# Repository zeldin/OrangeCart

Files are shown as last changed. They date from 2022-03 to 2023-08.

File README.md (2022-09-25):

The Orange Cartridge -- an FPGA cartridge for the C64/C128
==========================================================

This is an open source hardware FPGA cartridge for the C64 and C128.
The main features are:
 * ECP5 FPGA with 24k LUTs and 126 KB of block RAM
 * 16 MB of HyperRAM
 * 16 MB of SPI NOR Flash
 * Full speed USB
 * Micro SD-card
 * RGB LED
 * Pushbutton

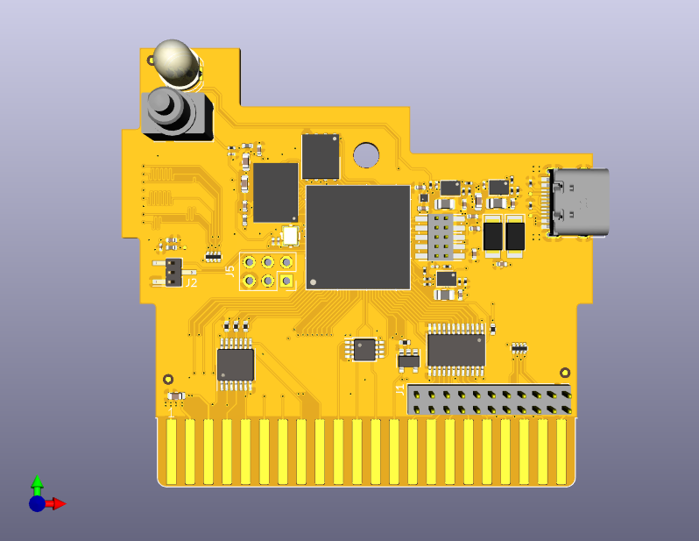
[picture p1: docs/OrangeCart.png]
Render of the PCBA


Usage
-----

For full usage instructions and other detailed information, please refer to
[the wiki][wiki].

The cartridge can be powered from the expansion port, from the USB connector,
or both at once (back-current protection diodes are present at each power
input).

To enter the bootloader, keep the pushbutton pressed down when applying
power.  The LED will start flashing in a rainbow pattern.  A new bitstream
can now be uploaded using DFU.

Example bitstreams
------------------

- [RVCop64](https://github.com/zeldin/RVCop64)
- [super-reu](https://github.com/zeldin/super-reu)

[wiki]: https://github.com/zeldin/OrangeCart/wiki

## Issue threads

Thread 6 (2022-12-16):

VIC access?

pottendo, 2022-12-16:
hi,
trying to control some VIC regs from RVCop64 firmware (bare metal, Zephyr, Linux) won't deliver the desired result.
It seems that the VIC registers aren't accessible reliably.
Attached my test program, derived from the oled example.
The access to video mem works, but the border color isn't changed - even worse, also the background is altered.
What am I doing wrong?

thx, pottendo
```
#include <stdio.h>
#include <stdlib.h>
#include <string.h>
#include <unistd.h>
#include <irq.h>
#include <libbase/uart.h>
#include <libbase/i2c.h>
#include <generated/csr.h>

volatile uint8_t *scr = (uint8_t*)0x00000420;
volatile uint8_t *vic = (uint8_t*)0x0000d000;
const int cnt = 3000;

int main(void)
{
#ifdef CONFIG_CPU_HAS_INTERRUPT
	irq_setmask(0);
	irq_setie(1);
#endif
	uart_init();
	uint8_t c = 0;
	volatile double f=1.2;
	printf("Starting...\n");
	*vic = 5;

	while (1)
	{
	    for (int i = 0; i < 128; i++)
	    {
		c = (c + 1) % 255;
		*(scr + i) = c;
		for (volatile int j = 0; j < cnt; j++)
		    ;
		(*vic) = ((*vic) + 1) % 16;
	    }
	    printf("hello world: %d, f=%f.\n", c, f);
	    f = f*1.033;
	}
	return 0;
}
```

zeldin, 2022-12-16:
Is this on regular RVCop or your SMP remix?  (And either way shouldn't the issue be opened in RVCop instead?)

When I run the commands
```
mem_write 0xd020 0xc 1 1
mem_write 0xd021 0x6 1 1
mem_read 0xd020 2 1
```
in `rvterm` on the release RVCop bitstream found on github, the results are the expected:
 * The first write changes only the border colour
 * The second write changes only the background colour
 * The read command reads back the values I wrote, but with the high nybble changed to 0xf
So I'd say VIC access is working fine.

Looking at your code, I don't see anything that attempts to change the border colour, only the colour of the first sprite?

pottendo, 2022-12-17:
Hi,
sorry, i've mixed up some of my experiments.
You're right, this test was around moving sprites - again attached my altered testprogram and here the demonstration:
  https://photos.app.goo.gl/WwHV2yNQAhuR5Moq6

The program is built using RVCop64/examples/oled, so SW without operating system.
I've used the bitstream, you've provided me on Oct. 30'th:
``` python3 bitstream.py --platform orangecart --uart usb_acm --sys-clk-freq 80e6  ```

What the program should do (at least I think):
- enable move spr0 horizontally: works in the beginning
- switch border color: works
- write some chars into video mem: works
- the program is slowed down by some busy-loops, to give the C64 some cycle times.
You see the border-color altered and the sprite moving, but all of a sudden, some other sprites appear (at ~0:08) and a few seconds disappear. Then even the  background color changes (at ~0:21), which continues to happen irregularly. Sometimes (not shown in the video), VIC is disabled. The C64 remains responsive, even run/stop-restore works to bring back the blue-screen in case of disabled VIC.

This is a C64, 250407 board, which passes the mem-tests (as reported here: https://github.com/zeldin/OrangeCart/discussions/2) with 80Mhz. with 64Mhz it also fails (some KO reports on the BIOS memtest).
In the meantime my C64 (board 250425) was thoroughly tested with all kinds of test-harnesses (by a C64-Retro expert) incl. tests with easyflash3, super zaxxon and of course several mem-test programs. All tests pass without flaws.
I'm still waiting to borrow a C64C with a newer board (250469 most probably).

So my conclusion: At least on these 'breadboard' machines, VIC register access works in principle but may have some side effect on other registers (e.g. moving other sprites, setting some registers, such as background color, disable VIC, etc.).
Maybe it's the VICII model, which makes the difference to your setup...

Thanks for listening, maybe you have some further ideas.
bye, pottendo

PS: I saw similar effects on Linux (on VexRiscV-SMP) and Zephyr (on your bitstream), with different programs, so the bitstream seems not to be significant for this observations
```
#include <stdio.h>
#include <stdlib.h>
#include <string.h>
#include <unistd.h>
#include <irq.h>
#include <libbase/uart.h>
#include <libbase/i2c.h>
#include <generated/csr.h>

volatile char *scr = (char *)0x00000420;
volatile char *vic = (char *)0x0000d000;
volatile char *sprsel = (char *)0x000003f8;
const int cnt = 30000; // adjust to check: with 300 c64 crashes pretty soon, 3000 is already somwhow stable.

int main(void)
{
#ifdef CONFIG_CPU_HAS_INTERRUPT
	irq_setmask(0);
	irq_setie(1);
#endif
	uart_init();
	uint8_t c = 0;
	*(vic+1) = 100;
	*sprsel = 1; // somewhere zeopage shouldb't be empty
	*(vic+0x27) = 1; // spr0, white
	*(vic+21) = 255; // enable all sprites

	while (1)
	{
	    for (int i = 0; i < 128; i++)
	    {
		c = (c + 1) % 255;
		*(scr + i) = c;
		// slow down
		for (volatile int j = 0; j < cnt; j++)
		    ;
		char d = ((*(vic+0x20)) + 1) % 16;
		// give some time between read and write
		for (volatile int j = 0; j < 300; j++)
		    ;
		(*(vic+0x20)) = d;
		// should move sprite 0, but some times switches off screen
		(*vic) = (*vic) + 1;
	    }
	}
	return 0;
}
```

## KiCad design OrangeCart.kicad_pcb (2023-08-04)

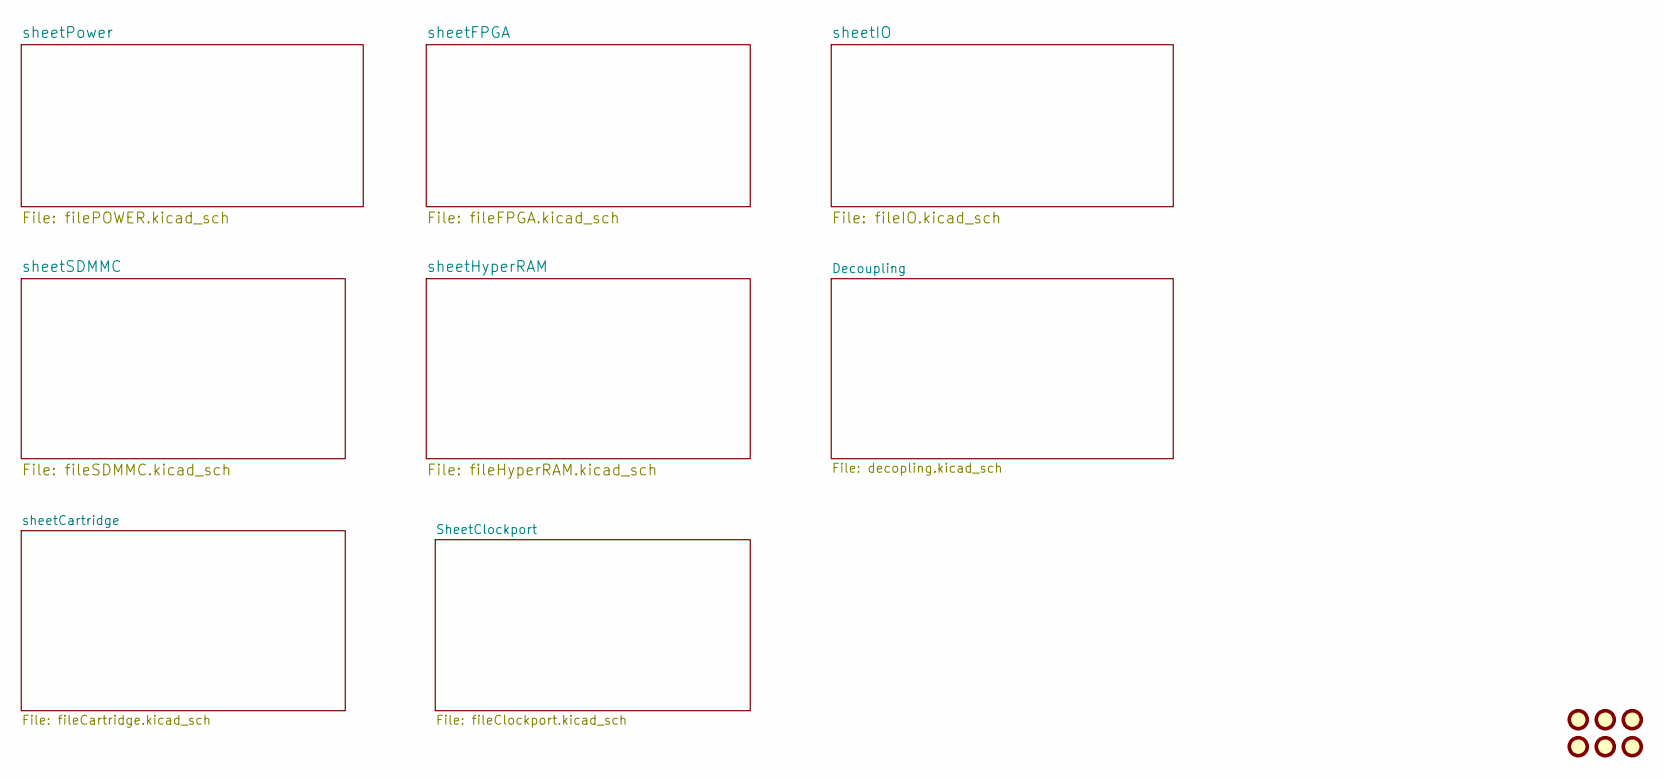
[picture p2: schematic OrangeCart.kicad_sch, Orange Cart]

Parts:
FID1, FID2, FID3, FID4, FID5, FID6: Fiducial; Fiducial_0.75mm_Mask1.5mm

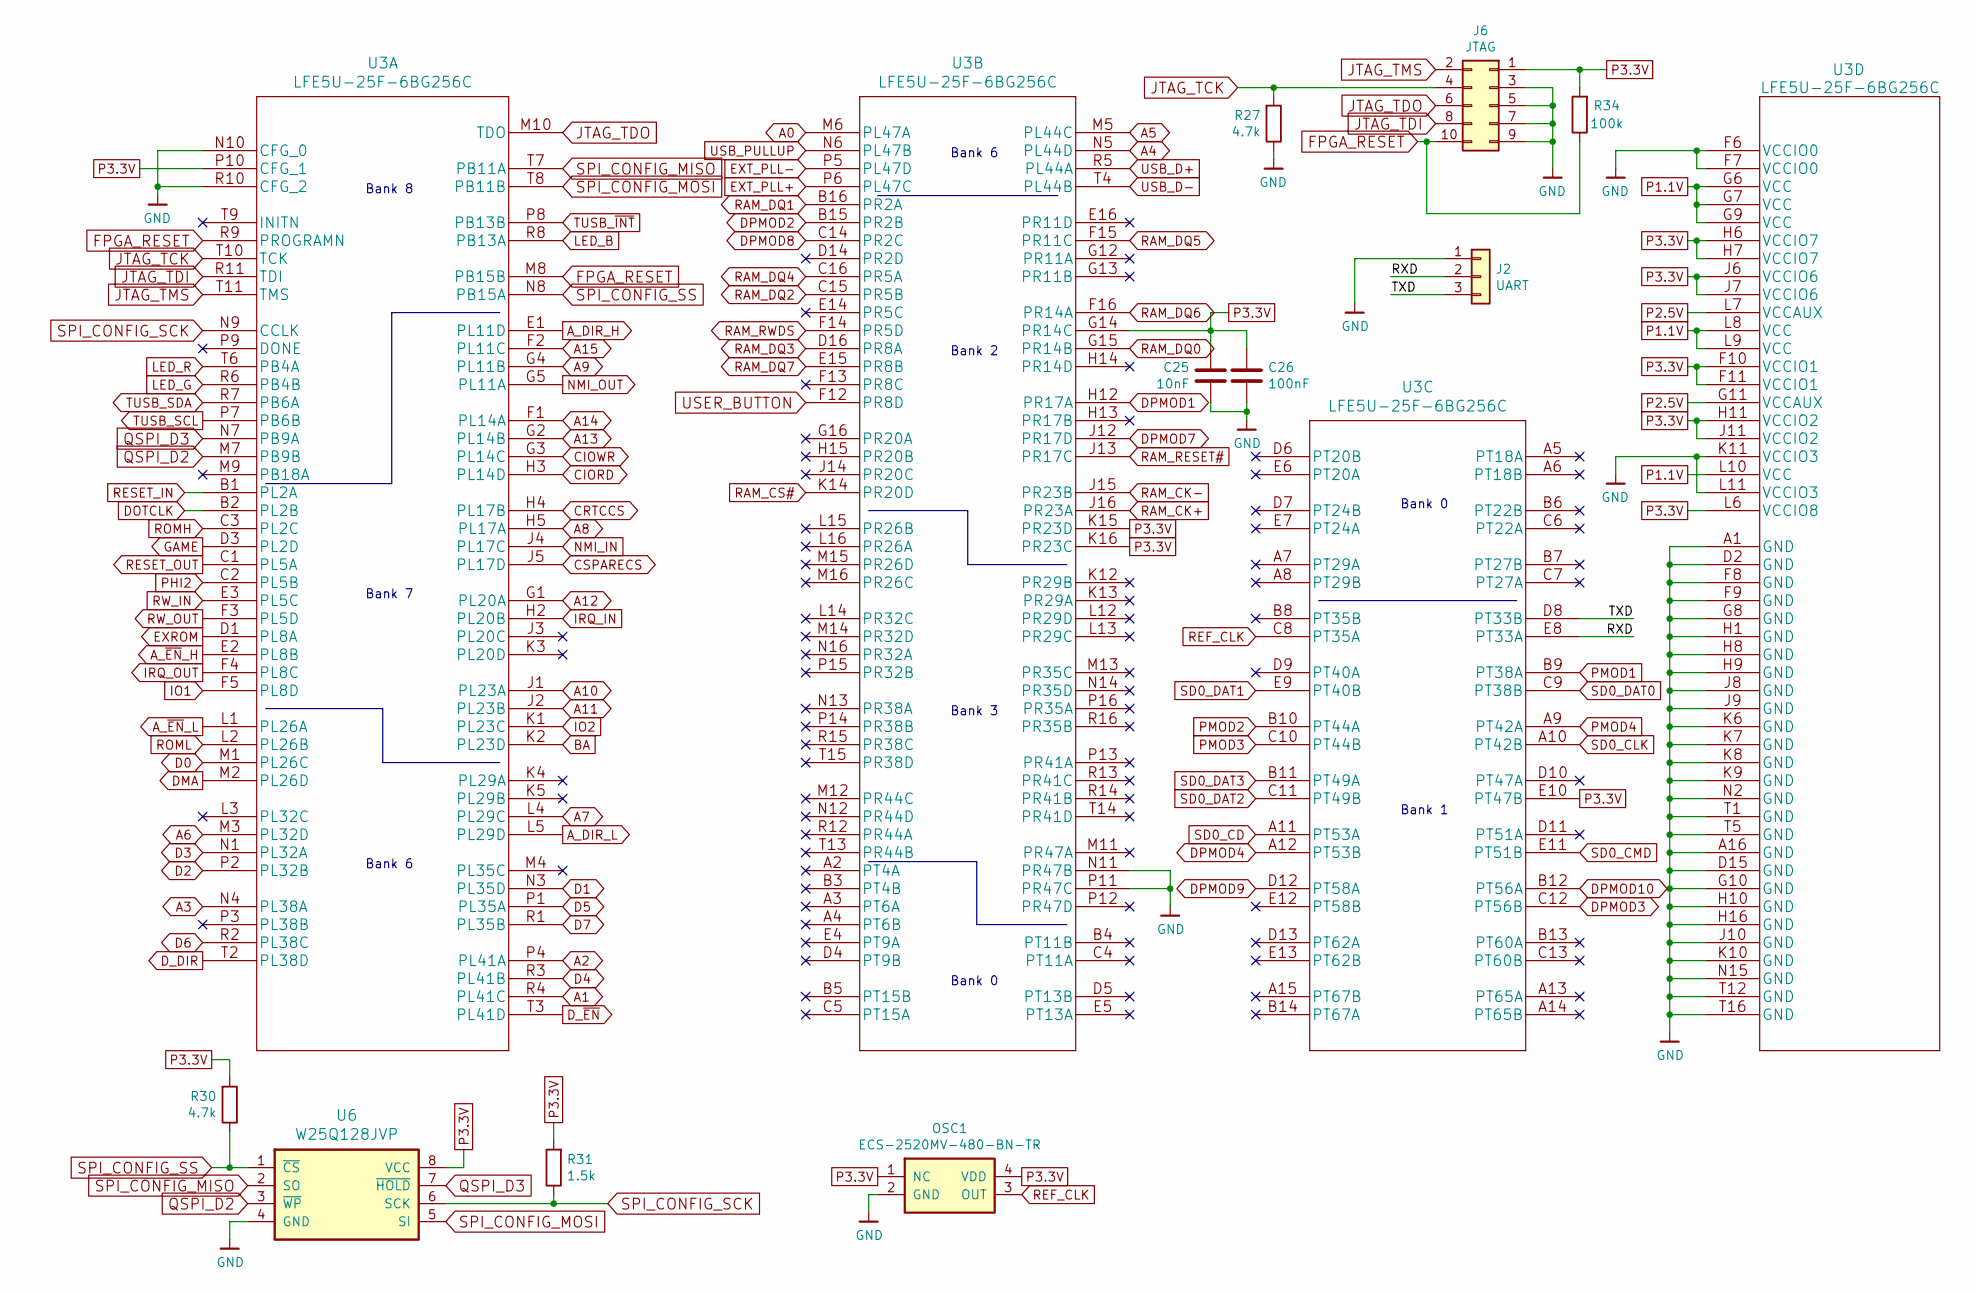
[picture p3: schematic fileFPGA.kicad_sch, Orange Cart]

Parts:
C25: 10nF; C_0201_0603Metric; Mouser Part No 187-CL03B103KP3NNNC
C26: 100nF; C_0201_0603Metric; Mouser Part No 187-CL03A104KQ3NNNC
J2: UART; PinHeader_1x03_P1.27mm_Vertical_SMD_Pin1Right; Mouser Part No 855-M50-3630342
J6: JTAG; FTSH-105-XX-X-DV; Mouser Part No 200-FTS10502LDVP
OSC1: ECS-2520MV-480-BN-TR; Oscillator_SMD_ECS_2520MV-xxx-xx-4Pin_2.5x2.0mm; Mouser Part No 520-2520MV-480-BN-T
R27, R30: 4.7k; R_0201_0603Metric; Mouser Part No 603-RC0201FR-074K7L
R31: 1.5k; R_0201_0603Metric; Mouser Part No 603-RC0201FR-071K5L / 667-ERJ-1GNF1501C
R34: 100k; R_0201_0603Metric; Mouser Part No 603-RC0201FR-07100KL / 667-ERJ-1GNF1003C
U3: LFE5U-25F-6BG256C; LFE5U-25F-8BG256C; Mouser Part No 842-LFE5U25F6BG256C
U6: W25Q128JVP; WSON-8-1EP_6x5mm_P1.27mm_EP3.4x4mm; Mouser Part No 454-W25Q128JVPIQTR

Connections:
/sheetFPGA/RXD: J2.2, U3.E8 (PT33A)
/sheetFPGA/TXD: J2.3, U3.D8 (PT33B)
A0: U3.M6 (PL47A); also elsewhere on the board
A1: U3.R4 (PL41C); also elsewhere on the board
A2: U3.P4 (PL41A); also elsewhere on the board
A3: U3.N4 (PL38A); also elsewhere on the board
A4: U3.N5 (PL44D); also elsewhere on the board
A5: U3.M5 (PL44C); also elsewhere on the board
A6: U3.M3 (PL32D); also elsewhere on the board
A7: U3.L4 (PL29C); also elsewhere on the board
A8: U3.H5 (PL17A); also elsewhere on the board
A9: U3.G4 (PL11B); also elsewhere on the board
A10: U3.J1 (PL23A); also elsewhere on the board
A11: U3.J2 (PL23B); also elsewhere on the board
A12: U3.G1 (PL20A); also elsewhere on the board
A13: U3.G2 (PL14B); also elsewhere on the board
A14: U3.F1 (PL14A); also elsewhere on the board
A15: U3.F2 (PL11C); also elsewhere on the board
A_DIR_H: U3.E1 (PL11D); also elsewhere on the board
A_DIR_L: U3.L5 (PL29D); also elsewhere on the board
A_~EN_H: U3.E2 (PL8B); also elsewhere on the board
A_~EN_L: U3.L1 (PL26A); also elsewhere on the board
BA: U3.K2 (PL23D); also elsewhere on the board
CIORD: U3.H3 (PL14D); also elsewhere on the board
CIOWR: U3.G3 (PL14C); also elsewhere on the board
CRTCCS: U3.H4 (PL17B); also elsewhere on the board
CSPARECS: U3.J5 (PL17D); also elsewhere on the board
D0: U3.M1 (PL26C); also elsewhere on the board
D1: U3.N3 (PL35D); also elsewhere on the board
D2: U3.P2 (PL32B); also elsewhere on the board
D3: U3.N1 (PL32A); also elsewhere on the board
D4: U3.R3 (PL41B); also elsewhere on the board
D5: U3.P1 (PL35A); also elsewhere on the board
D6: U3.R2 (PL38C); also elsewhere on the board
D7: U3.R1 (PL35B); also elsewhere on the board
DMA: U3.M2 (PL26D); also elsewhere on the board
DOTCLK: U3.B2 (PL2B); also elsewhere on the board
DPMOD1: U3.H12 (PR17A); also elsewhere on the board
DPMOD2: U3.B15 (PR2B); also elsewhere on the board
DPMOD3: U3.C12 (PT56B); also elsewhere on the board
DPMOD4: U3.A12 (PT53B); also elsewhere on the board
DPMOD7: U3.J12 (PR17D); also elsewhere on the board
DPMOD8: U3.C14 (PR2C); also elsewhere on the board
DPMOD9: U3.D12 (PT58A); also elsewhere on the board
DPMOD10: U3.B12 (PT56A); also elsewhere on the board
D_DIR: U3.T2 (PL38D); also elsewhere on the board
D_~EN: U3.T3 (PL41D); also elsewhere on the board
EXROM: U3.D1 (PL8A); also elsewhere on the board
EXT_PLL+: U3.P6 (PL47C); also elsewhere on the board
EXT_PLL-: U3.P5 (PL47D); also elsewhere on the board
FPGA_RESET: J6.10, R34.1, U3.M8 (PB15B), U3.R9 (PROGRAMN)
GAME: U3.D3 (PL2D); also elsewhere on the board
GND: C25.2, C26.2, J2.1, J6.3, J6.5, J6.7, J6.9, OSC1.2 (GND), R27.1, U3.A1 (GND), U3.A16 (GND), U3.D2 (GND), U3.D15 (GND), U3.F6 (VCCIO0), U3.F7 (VCCIO0), U3.F8 (GND), U3.F9 (GND), U3.G8 (GND), U3.G10 (GND), U3.H1 (GND), U3.H8 (GND), U3.H9 (GND), U3.H10 (GND), U3.H16 (GND), U3.J8 (GND), U3.J9 (GND), U3.J10 (GND), U3.K6 (GND), U3.K7 (GND), U3.K8 (GND), U3.K9 (GND), U3.K10 (GND), U3.K11 (VCCIO3), U3.L11 (VCCIO3), U3.N2 (GND), U3.N10 (CFG_0), U3.N11 (PR47B), U3.N15 (GND), U3.P11 (PR47C), U3.R10 (CFG_2), U3.T1 (GND), U3.T5 (GND), U3.T12 (GND), U3.T16 (GND), U6.4 (GND); also elsewhere on the board
IO1: U3.F5 (PL8D); also elsewhere on the board
IO2: U3.K1 (PL23C); also elsewhere on the board
IRQ_IN: U3.H2 (PL20B); also elsewhere on the board
IRQ_OUT: U3.F4 (PL8C); also elsewhere on the board
JTAG_TCK: J6.4, R27.2, U3.T10 (TCK)
JTAG_TDI: J6.8, U3.R11 (TDI)
JTAG_TDO: J6.6, U3.M10 (TDO)
JTAG_TMS: J6.2, U3.T11 (TMS)
LED_B: U3.R8 (PB13A); also elsewhere on the board
LED_G: U3.R6 (PB4B); also elsewhere on the board
LED_R: U3.T6 (PB4A); also elsewhere on the board
NMI_IN: U3.J4 (PL17C); also elsewhere on the board
NMI_OUT: U3.G5 (PL11A); also elsewhere on the board
P1.1V: U3.G6 (VCC), U3.G7 (VCC), U3.G9 (VCC), U3.L8 (VCC), U3.L9 (VCC), U3.L10 (VCC); also elsewhere on the board
P2.5V: U3.G11 (VCCAUX), U3.L7 (VCCAUX); also elsewhere on the board
P3.3V: C25.1, C26.1, J6.1, OSC1.1 (NC), OSC1.4 (VDD), R30.2, R31.2, R34.2, U3.E10 (PT47B), U3.F10 (VCCIO1), U3.F11 (VCCIO1), U3.G14 (PR14C), U3.H6 (VCCIO7), U3.H7 (VCCIO7), U3.H11 (VCCIO2), U3.J6 (VCCIO6), U3.J7 (VCCIO6), U3.J11 (VCCIO2), U3.K15 (PR23D), U3.K16 (PR23C), U3.L6 (VCCIO8), U3.P10 (CFG_1), U6.8 (VCC); also elsewhere on the board
PHI2: U3.C2 (PL5B); also elsewhere on the board
PMOD1: U3.B9 (PT38A); also elsewhere on the board
PMOD2: U3.B10 (PT44A); also elsewhere on the board
PMOD3: U3.C10 (PT44B); also elsewhere on the board
PMOD4: U3.A9 (PT42A); also elsewhere on the board
QSPI_D2: U3.M7 (PB9B), U6.3 (~WP)
QSPI_D3: U3.N7 (PB9A), U6.7 (~HOLD)
RAM_CK+: U3.J16 (PR23A); also elsewhere on the board
RAM_CK-: U3.J15 (PR23B); also elsewhere on the board
RAM_CS#: U3.K14 (PR20D); also elsewhere on the board
RAM_DQ0: U3.G15 (PR14B); also elsewhere on the board
RAM_DQ1: U3.B16 (PR2A); also elsewhere on the board
RAM_DQ2: U3.C15 (PR5B); also elsewhere on the board
RAM_DQ3: U3.D16 (PR8A); also elsewhere on the board
RAM_DQ4: U3.C16 (PR5A); also elsewhere on the board
RAM_DQ5: U3.F15 (PR11C); also elsewhere on the board
RAM_DQ6: U3.F16 (PR14A); also elsewhere on the board
RAM_DQ7: U3.E15 (PR8B); also elsewhere on the board
RAM_RESET#: U3.J13 (PR17C); also elsewhere on the board
RAM_RWDS: U3.F14 (PR5D); also elsewhere on the board
REF_CLK: OSC1.3 (OUT), U3.C8 (PT35A)
RESET_IN: U3.B1 (PL2A); also elsewhere on the board
RESET_OUT: U3.C1 (PL5A); also elsewhere on the board
ROMH: U3.C3 (PL2C); also elsewhere on the board
ROML: U3.L2 (PL26B); also elsewhere on the board
RW_IN: U3.E3 (PL5C); also elsewhere on the board
RW_OUT: U3.F3 (PL5D); also elsewhere on the board
SD0_CD: U3.A11 (PT53A); also elsewhere on the board
SD0_CLK: U3.A10 (PT42B); also elsewhere on the board
SD0_CMD: U3.E11 (PT51B); also elsewhere on the board
SD0_DAT0: U3.C9 (PT38B); also elsewhere on the board
SD0_DAT1: U3.E9 (PT40B); also elsewhere on the board
SD0_DAT2: U3.C11 (PT49B); also elsewhere on the board
SD0_DAT3: U3.B11 (PT49A); also elsewhere on the board
SPI_CONFIG_MISO: U3.T7 (PB11A), U6.2 (SO)
SPI_CONFIG_MOSI: U3.T8 (PB11B), U6.5 (SI)
SPI_CONFIG_SCK: R31.1, U3.N9 (CCLK), U6.6 (SCK)
SPI_CONFIG_SS: R30.1, U3.N8 (PB15A), U6.1 (~CS)
TUSB_SCL: U3.P7 (PB6B); also elsewhere on the board
TUSB_SDA: U3.R7 (PB6A); also elsewhere on the board
TUSB_~INT: U3.P8 (PB13B); also elsewhere on the board
USB_D+: U3.R5 (PL44A); also elsewhere on the board
USB_D-: U3.T4 (PL44B); also elsewhere on the board
USB_PULLUP: U3.N6 (PL47B); also elsewhere on the board
USER_BUTTON: U3.F12 (PR8D); also elsewhere on the board

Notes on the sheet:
Bank 6
Bank 7
Bank 1
Bank 8
Bank 0
Bank 3
Bank 2

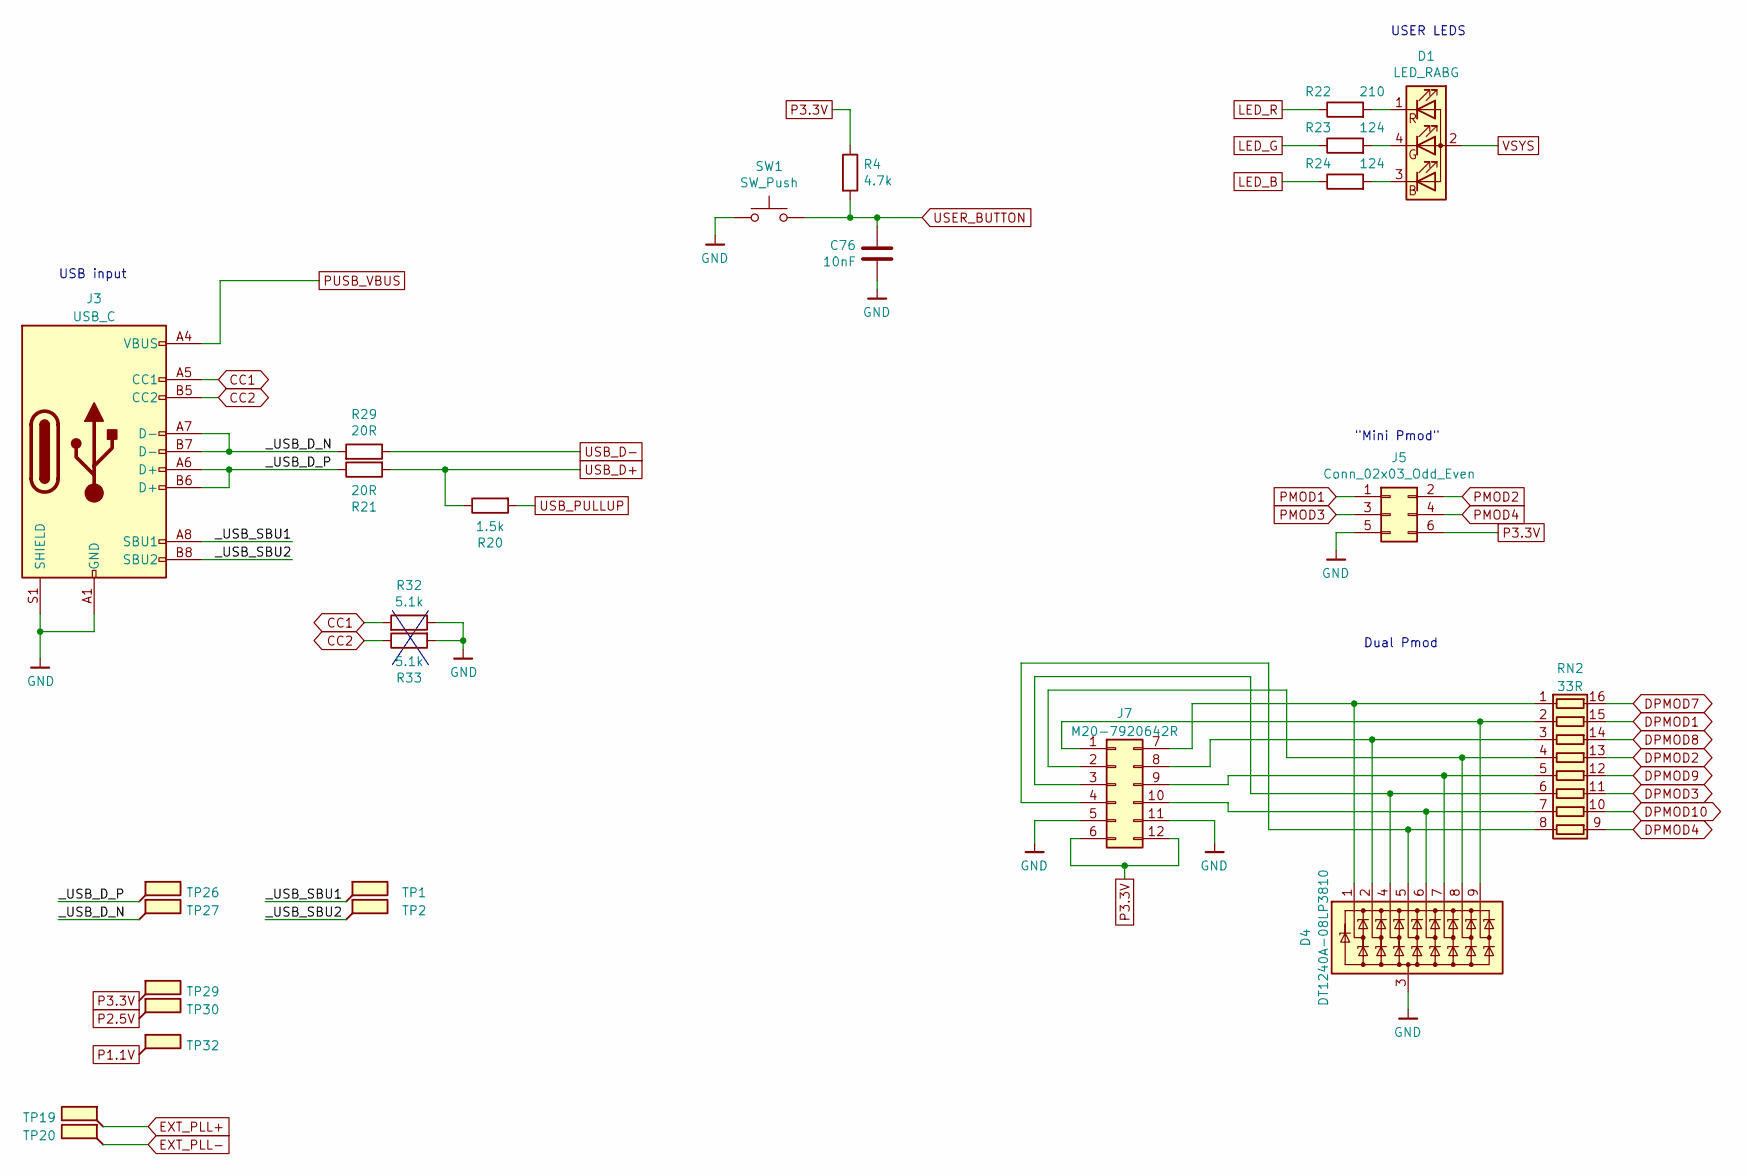
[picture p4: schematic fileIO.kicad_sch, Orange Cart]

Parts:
C76: 10nF; C_0201_0603Metric; Mouser Part No 187-CL03B103KP3NNNC
D1: LED_RABG; LED_D5.0mm-4_RGB; Mouser Part No 604-WP154A43VBDZGWCA
D4: DT1240A-08LP3810; UDFN-9_1.0x3.8mm_P0.5mm; Mouser Part No 621-DT1240A08LP38107
J3: USB_C; USB_C_Receptacle_HRO_TYPE-C-31-M-12; Mouser Part No 640-USB4105-GF-A-120
J5: Conn_02x03_Odd_Even; PinSocket_2x03_P2.54mm_Vertical
J7: M20-7920642R; M207920642R; Mouser Part No 855-M20-7920642R
R4: 4.7k; R_0201_0603Metric; Mouser Part No 603-RC0201FR-074K7L
R20: 1.5k; R_0201_0603Metric; Mouser Part No 603-RC0201FR-071K5L / 667-ERJ-1GNF1501C
R21, R29: 20R; R_0201_0603Metric; Mouser Part No 603-RC0201FR-0720RL
R22: 210; R_0402_1005Metric; Mouser Part No 667-ERJ-2RKF2100X
R23, R24: 124; R_0402_1005Metric; Mouser Part No 667-ERJ-2RKF1240X
R32, R33: 5.1k; R_0201_0603Metric; Mouser Part No 603-RC0201JR-075K1L
RN2: 33R; R_Array_Convex_8x0602; Mouser Part No 667-EXB-2HV330JV
SW1: SW_Push; TPB11CGPC004; Mouser Part No 506-TPB11CGPC004
TP1, TP2, TP19, TP20, TP26, TP27, TP29, TP30, TP32: SMD_TP; TestPoint_Pad_D0.5mm

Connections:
/sheetIO/_USB_D_N: J3.A7 (D-), J3.B7 (D-), R29.2, TP27.1
/sheetIO/_USB_D_P: J3.A6 (D+), J3.B6 (D+), R21.1, TP26.1
/sheetIO/_USB_SBU1: J3.A8 (SBU1), TP1.1
/sheetIO/_USB_SBU2: J3.B8 (SBU2), TP2.1
CC1: J3.A5 (CC1), R32.2; also elsewhere on the board
CC2: J3.B5 (CC2), R33.1; also elsewhere on the board
DPMOD1: RN2.15 (R2.2); also elsewhere on the board
DPMOD2: RN2.13 (R4.2); also elsewhere on the board
DPMOD3: RN2.11 (R6.2); also elsewhere on the board
DPMOD4: RN2.9 (R8.2); also elsewhere on the board
DPMOD7: RN2.16 (R1.2); also elsewhere on the board
DPMOD8: RN2.14 (R3.2); also elsewhere on the board
DPMOD9: RN2.12 (R5.2); also elsewhere on the board
DPMOD10: RN2.10 (R7.2); also elsewhere on the board
EXT_PLL+: TP19.1; also elsewhere on the board
EXT_PLL-: TP20.1; also elsewhere on the board
GND: C76.2, D4.3 (A), J3.A1 (GND), J3.A12 (GND), J3.B1 (GND), J3.B12 (GND), J3.S1 (SHIELD), J5.5, J7.5, J7.11, R32.1, R33.2, SW1.1; also elsewhere on the board
LED_B: R24.1; also elsewhere on the board
LED_G: R23.1; also elsewhere on the board
LED_R: R22.1; also elsewhere on the board
unnamed: D1.3 (BK), R24.2
unnamed: D1.4 (GK), R23.2
unnamed: D1.1 (RK), R22.2
unnamed: D4.1 (K1), J7.7, RN2.1 (R1.1)
unnamed: D4.2 (K2), J7.8, RN2.3 (R3.1)
unnamed: D4.4 (K3), J7.3, RN2.6 (R6.1)
unnamed: D4.5 (K4), J7.4, RN2.8 (R8.1)
unnamed: D4.6 (K5), J7.10, RN2.7 (R7.1)
unnamed: D4.7 (K6), J7.9, RN2.5 (R5.1)
unnamed: D4.8 (K7), J7.2, RN2.4 (R4.1)
unnamed: D4.9 (K8), J7.1, RN2.2 (R2.1)
P1.1V: TP32.1; also elsewhere on the board
P2.5V: TP30.1; also elsewhere on the board
P3.3V: J5.6, J7.6, J7.12, R4.1, TP29.1; also elsewhere on the board
PMOD1: J5.1; also elsewhere on the board
PMOD2: J5.2; also elsewhere on the board
PMOD3: J5.3; also elsewhere on the board
PMOD4: J5.4; also elsewhere on the board
PUSB_VBUS: J3.A4 (VBUS), J3.A9 (VBUS), J3.B4 (VBUS), J3.B9 (VBUS); also elsewhere on the board
USB_D+: R20.1, R21.2; also elsewhere on the board
USB_D-: R29.1; also elsewhere on the board
USB_PULLUP: R20.2; also elsewhere on the board
USER_BUTTON: C76.1, R4.2, SW1.2; also elsewhere on the board
VSYS: D1.2 (A); also elsewhere on the board

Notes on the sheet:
Dual Pmod
USER LEDS
USB input
"Mini Pmod"

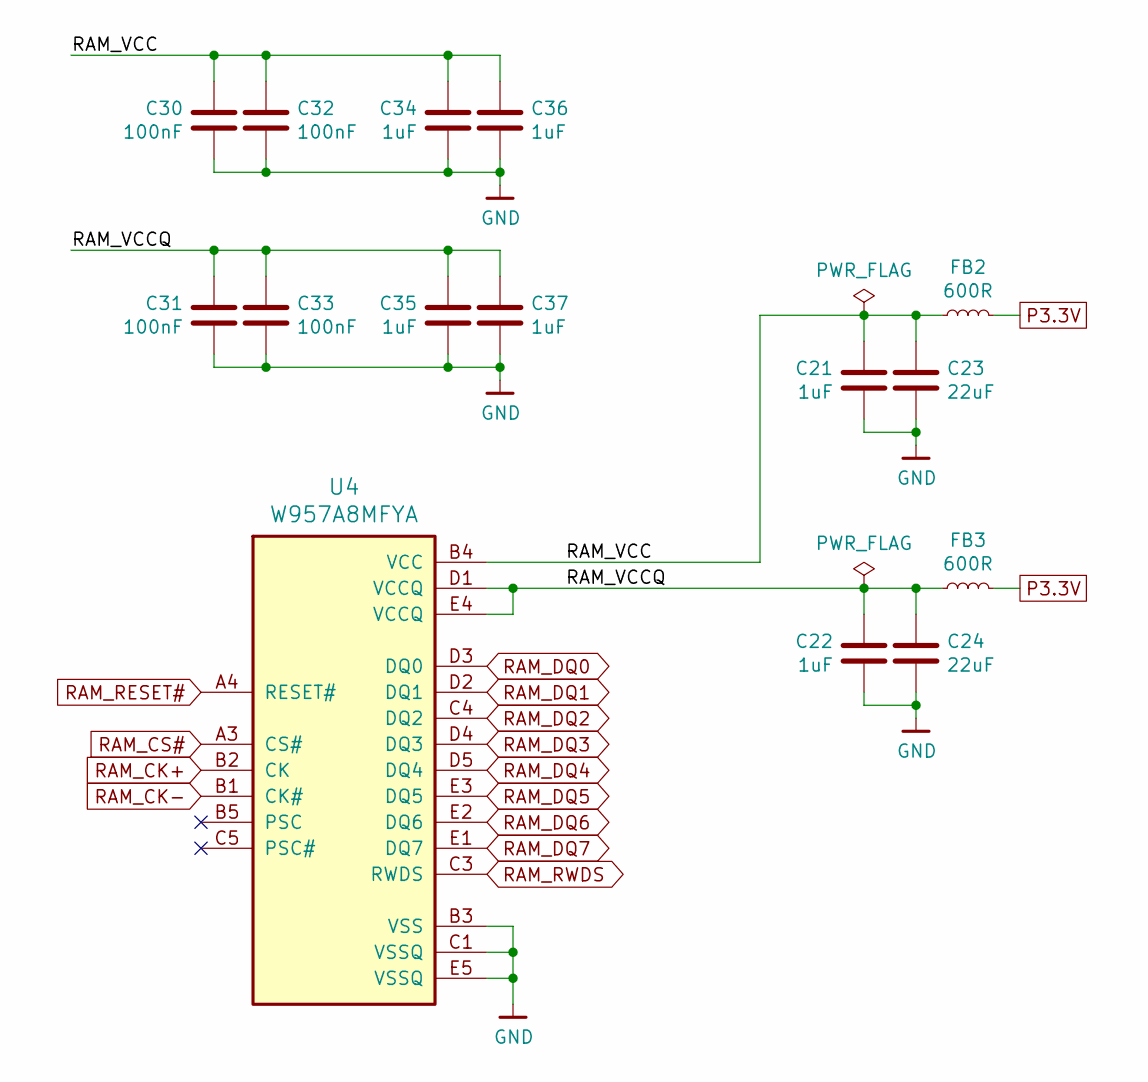
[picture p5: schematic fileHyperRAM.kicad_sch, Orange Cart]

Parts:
C21, C22, C34, C35, C36, C37: 1uF; C_0402_1005Metric; Mouser Part No 963-JMK105C6105KV-F
C23, C24: 22uF; C_0603_1608Metric; Mouser Part No 81-GRM188R60J226ME0D / 81-GRM188R60J226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
C30, C31, C32, C33: 100nF; C_0201_0603Metric; Mouser Part No 187-CL03A104KQ3NNNC
FB2, FB3: 600R; L_0402_1005Metric; Mouser Part No 81-BLM15AG601SN1D
U4: W957A8MFYA; T-PBGA-24_6.0x8.0mm_Layout5x5_P1.0mm; Mouser Part No 454-W957A8MFYA5I

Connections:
/sheetHyperRAM/RAM_VCC: C21.1, C23.1, C30.1, C32.1, C34.1, C36.1, FB2.1, U4.B4 (VCC)
/sheetHyperRAM/RAM_VCCQ: C22.1, C24.1, C31.1, C33.1, C35.1, C37.1, FB3.1, U4.D1 (VCCQ), U4.E4 (VCCQ)
GND: C21.2, C22.2, C23.2, C24.2, C30.2, C31.2, C32.2, C33.2, C34.2, C35.2, C36.2, C37.2, U4.B3 (VSS), U4.C1 (VSSQ), U4.E5 (VSSQ); also elsewhere on the board
P3.3V: FB2.2, FB3.2; also elsewhere on the board
RAM_CK+: U4.B2 (CK); also elsewhere on the board
RAM_CK-: U4.B1 (CK#); also elsewhere on the board
RAM_CS#: U4.A3 (CS#); also elsewhere on the board
RAM_DQ0: U4.D3 (DQ0); also elsewhere on the board
RAM_DQ1: U4.D2 (DQ1); also elsewhere on the board
RAM_DQ2: U4.C4 (DQ2); also elsewhere on the board
RAM_DQ3: U4.D4 (DQ3); also elsewhere on the board
RAM_DQ4: U4.D5 (DQ4); also elsewhere on the board
RAM_DQ5: U4.E3 (DQ5); also elsewhere on the board
RAM_DQ6: U4.E2 (DQ6); also elsewhere on the board
RAM_DQ7: U4.E1 (DQ7); also elsewhere on the board
RAM_RESET#: U4.A4 (RESET#); also elsewhere on the board
RAM_RWDS: U4.C3 (RWDS); also elsewhere on the board

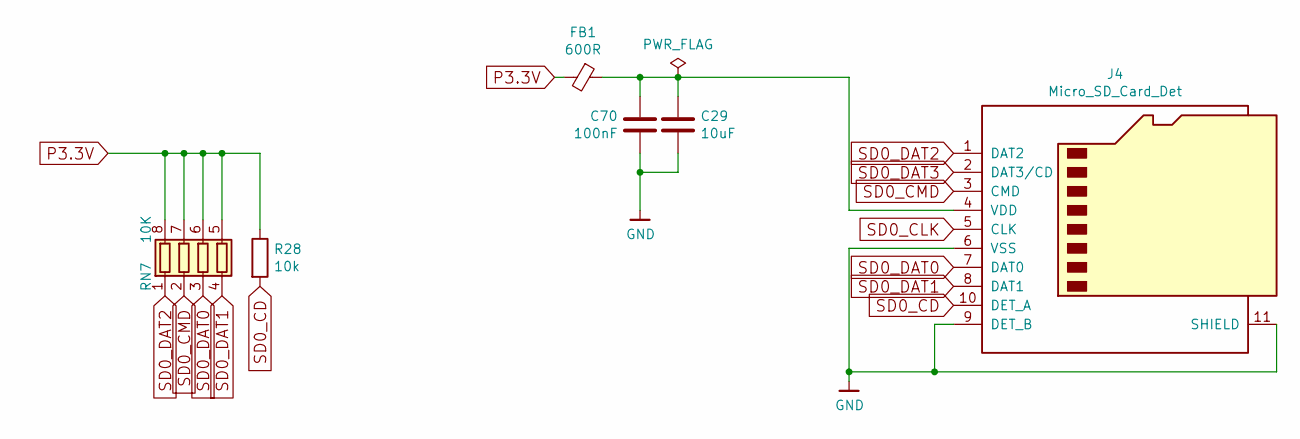
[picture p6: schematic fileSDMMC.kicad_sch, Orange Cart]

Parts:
C29: 10uF; C_0402_1005Metric; Mouser Part No 81-GRM155R60J106ME5D
C70: 100nF; C_0201_0603Metric; Mouser Part No 187-CL03A104KQ3NNNC
FB1: 600R; L_0402_1005Metric; Mouser Part No 81-BLM15AG601SN1D
J4: Micro_SD_Card_Det; SDCARD_MOLEX_503398-1892; Mouser Part No 538-503398-1892
R28: 10k; R_0201_0603Metric; Mouser Part No 603-RC0201FR-0710KL
RN7: 10K; R_Array_Convex_4x0402; Mouser Part No 667-EXB-28V103JX

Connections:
GND: C29.1, C70.1, J4.6 (VSS), J4.9 (DET_B), J4.11 (SHIELD); also elsewhere on the board
unnamed: C29.2, C70.2, FB1.1, J4.4 (VDD)
P3.3V: FB1.2, R28.1, RN7.5 (R4.2), RN7.6 (R3.2), RN7.7 (R2.2), RN7.8 (R1.2); also elsewhere on the board
SD0_CD: J4.10 (DET_A), R28.2; also elsewhere on the board
SD0_CLK: J4.5 (CLK); also elsewhere on the board
SD0_CMD: J4.3 (CMD), RN7.2 (R2.1); also elsewhere on the board
SD0_DAT0: J4.7 (DAT0), RN7.3 (R3.1); also elsewhere on the board
SD0_DAT1: J4.8 (DAT1), RN7.4 (R4.1); also elsewhere on the board
SD0_DAT2: J4.1 (DAT2), RN7.1 (R1.1); also elsewhere on the board
SD0_DAT3: J4.2 (DAT3/CD); also elsewhere on the board

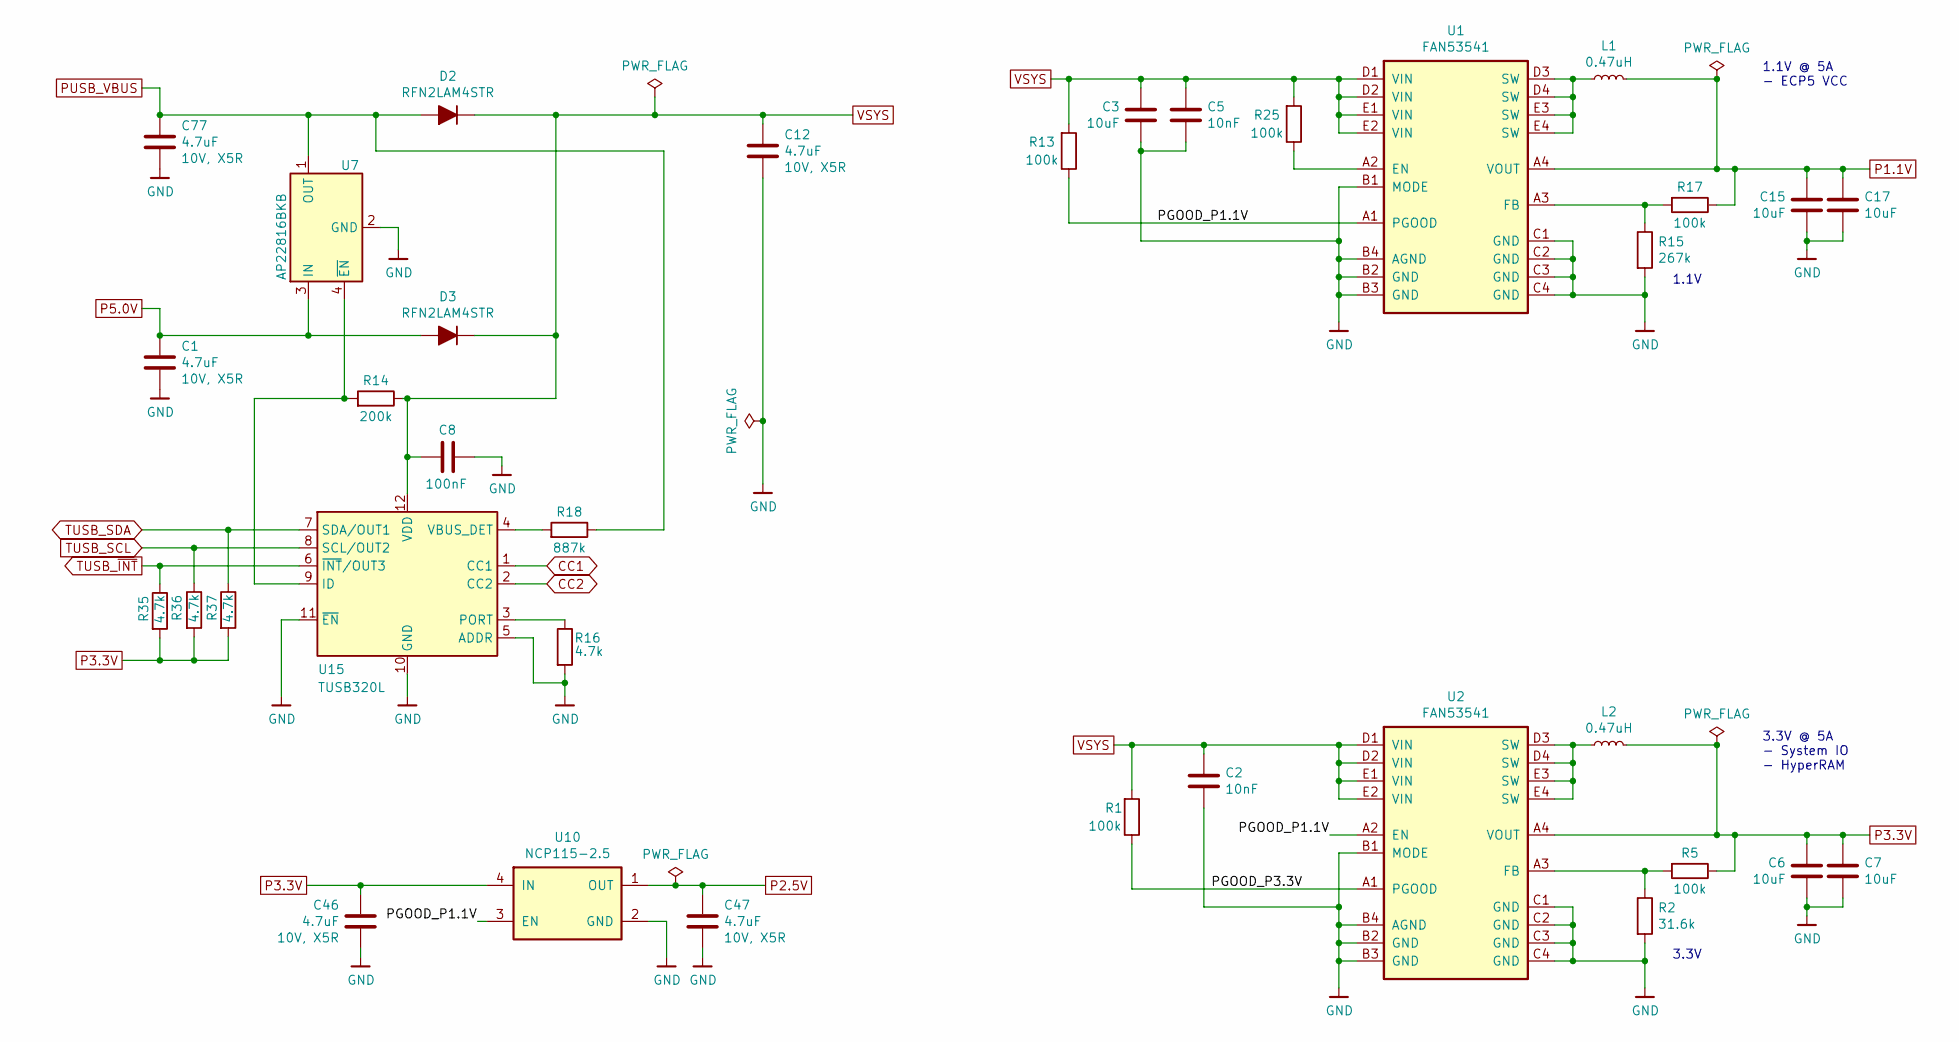
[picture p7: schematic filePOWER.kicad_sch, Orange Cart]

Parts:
C1, C12, C46, C47, C77: 4.7uF; C_0402_1005Metric; Mouser Part No 81-GRM155R61A475MEAD / 81-GRM155R61A475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
C2, C5: 10nF; C_0201_0603Metric; Mouser Part No 187-CL03B103KP3NNNC
C3: 10uF; C_0603_1608Metric; Mouser Part No 963-LMK107BBJ106MALT
C6, C7, C15, C17: 10uF; C_0402_1005Metric; Mouser Part No 81-GRM155R60J106ME5D
C8: 100nF; C_0201_0603Metric; Mouser Part No 187-CL03A104KQ3NNNC
D2, D3: RFN2LAM4STR; D_SOD-128; Mouser Part No 755-RFN2LAM4STR
L1, L2: 0.47uH; L_0805_2012Metric; Mouser Part No 187-CIGT201210UHR47M
R1, R5, R13, R17, R25: 100k; R_0201_0603Metric; Mouser Part No 603-RC0201FR-07100KL / 667-ERJ-1GNF1003C
R2: 31.6k; R_0201_0603Metric; Mouser Part No 603-RC0201FR-0731K6L
R14: 200k; R_0201_0603Metric; Mouser Part No 603-RC0201FR-07200KL
R15: 267k; R_0201_0603Metric; Mouser Part No 603-RC0201FR-07267KL / 667-ERJ-1GNF2673C
R16, R35, R36, R37: 4.7k; R_0402_1005Metric; Mouser Part No 603-RC0402JR-074K7L
R18: 887k; R_0201_0603Metric; Mouser Part No 603-RC0201FR-07887KL
U1, U2: FAN53541; WLCSP-20_1.934x2.434mm_Layout4x5_P0.4mm; Mouser Part No 512-FAN53541UCX
U7: AP22816BKB; SOT-23-5; Mouser Part No 621-AP22816BKBWT-7
U10: NCP115-2.5; Texas_X2SON-4_1x1mm_P0.65mm; Mouser Part No 863-NCP115CMX250TCG
U15: TUSB320L; Texas_X2QFN-12_1.6x1.6mm_P0.4mm; Mouser Part No 595-TUSB320LAIRWBR

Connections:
/sheetPower/PGOOD_P1.1V: R13.1, U1.A1 (PGOOD), U2.A2 (EN), U10.3 (EN)
/sheetPower/PGOOD_P3.3V: R1.1, U2.A1 (PGOOD)
CC1: U15.1 (CC1); also elsewhere on the board
CC2: U15.2 (CC2); also elsewhere on the board
GND: C1.2, C2.1, C3.1, C5.1, C6.1, C7.1, C8.2, C12.2, C15.1, C17.1, C46.2, C47.2, C77.2, R2.2, R15.2, R16.2, U1.B1 (MODE), U1.B2 (GND), U1.B3 (GND), U1.B4 (AGND), U1.C1 (GND), U1.C2 (GND), U1.C3 (GND), U1.C4 (GND), U2.B1 (MODE), U2.B2 (GND), U2.B3 (GND), U2.B4 (AGND), U2.C1 (GND), U2.C2 (GND), U2.C3 (GND), U2.C4 (GND), U7.2 (GND), U10.2 (GND), U15.5 (ADDR), U15.10 (GND), U15.11 (~EN); also elsewhere on the board
unnamed: L1.1, U1.D3 (SW), U1.D4 (SW), U1.E3 (SW), U1.E4 (SW)
unnamed: L2.1, U2.D3 (SW), U2.D4 (SW), U2.E3 (SW), U2.E4 (SW)
unnamed: R25.1, U1.A2 (EN)
unnamed: R15.1, R17.2, U1.A3 (FB)
unnamed: R2.1, R5.2, U2.A3 (FB)
unnamed: R14.2, U7.4 (~EN), U15.9 (ID)
unnamed: R16.1, U15.3 (PORT)
unnamed: R18.2, U15.4 (VBUS_DET)
P1.1V: C15.2, C17.2, L1.2, R17.1, U1.A4 (VOUT); also elsewhere on the board
P2.5V: C47.1, U10.1 (OUT); also elsewhere on the board
P3.3V: C6.2, C7.2, C46.1, L2.2, R5.1, R35.2, R36.2, R37.2, U2.A4 (VOUT), U10.4 (IN); also elsewhere on the board
P5.0V: C1.1, D3.2 (A), U7.3 (IN); also elsewhere on the board
PUSB_VBUS: C77.1, D2.2 (A), R18.1, U7.1 (OUT), U7.5 (OUT); also elsewhere on the board
TUSB_SCL: R36.1, U15.8 (SCL/OUT2); also elsewhere on the board
TUSB_SDA: R37.1, U15.7 (SDA/OUT1); also elsewhere on the board
TUSB_~INT: R35.1, U15.6 (~INT/OUT3); also elsewhere on the board
VSYS: C2.2, C3.2, C5.2, C8.1, C12.1, D2.1 (K), D3.1 (K), R1.2, R13.2, R14.1, R25.2, U1.D1 (VIN), U1.D2 (VIN), U1.E1 (VIN), U1.E2 (VIN), U2.D1 (VIN), U2.D2 (VIN), U2.E1 (VIN), U2.E2 (VIN), U15.12 (VDD); also elsewhere on the board

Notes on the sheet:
1.1V @ 5A - ECP5 VCC
1.1V
3.3V @ 5A - System IO - HyperRAM
3.3V

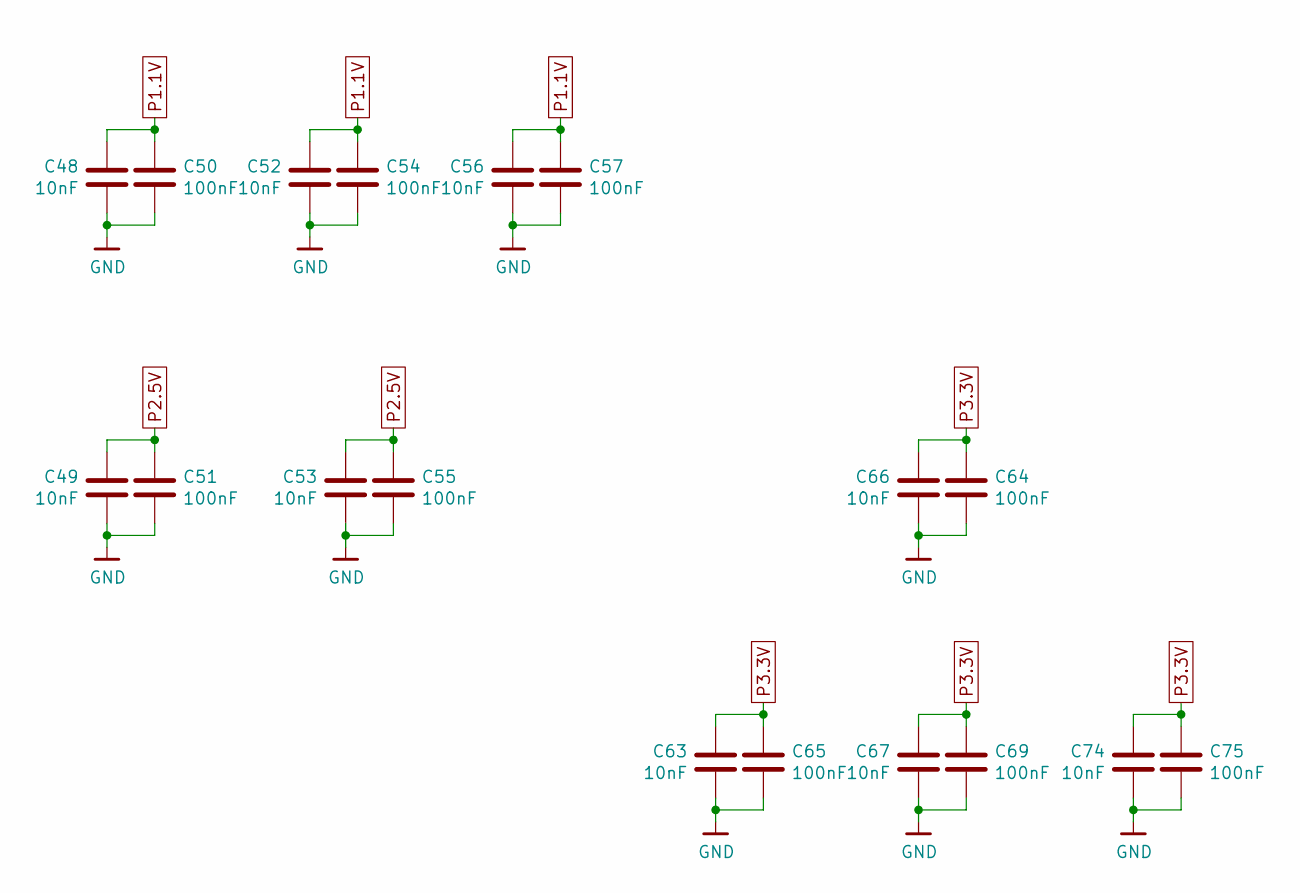
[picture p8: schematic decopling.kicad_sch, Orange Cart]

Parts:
C48, C49, C52, C53, C56, C63, C66, C67, C74: 10nF; C_0201_0603Metric; Mouser Part No 187-CL03B103KP3NNNC
C50, C51, C54, C55, C57, C64, C65, C69, C75: 100nF; C_0201_0603Metric; Mouser Part No 187-CL03A104KQ3NNNC

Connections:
GND: C48.2, C49.2, C50.2, C51.2, C52.2, C53.2, C54.2, C55.2, C56.2, C57.2, C63.2, C64.2, C65.2, C66.2, C67.2, C69.2, C74.2, C75.2; also elsewhere on the board
P1.1V: C48.1, C50.1, C52.1, C54.1, C56.1, C57.1; also elsewhere on the board
P2.5V: C49.1, C51.1, C53.1, C55.1; also elsewhere on the board
P3.3V: C63.1, C64.1, C65.1, C66.1, C67.1, C69.1, C74.1, C75.1; also elsewhere on the board

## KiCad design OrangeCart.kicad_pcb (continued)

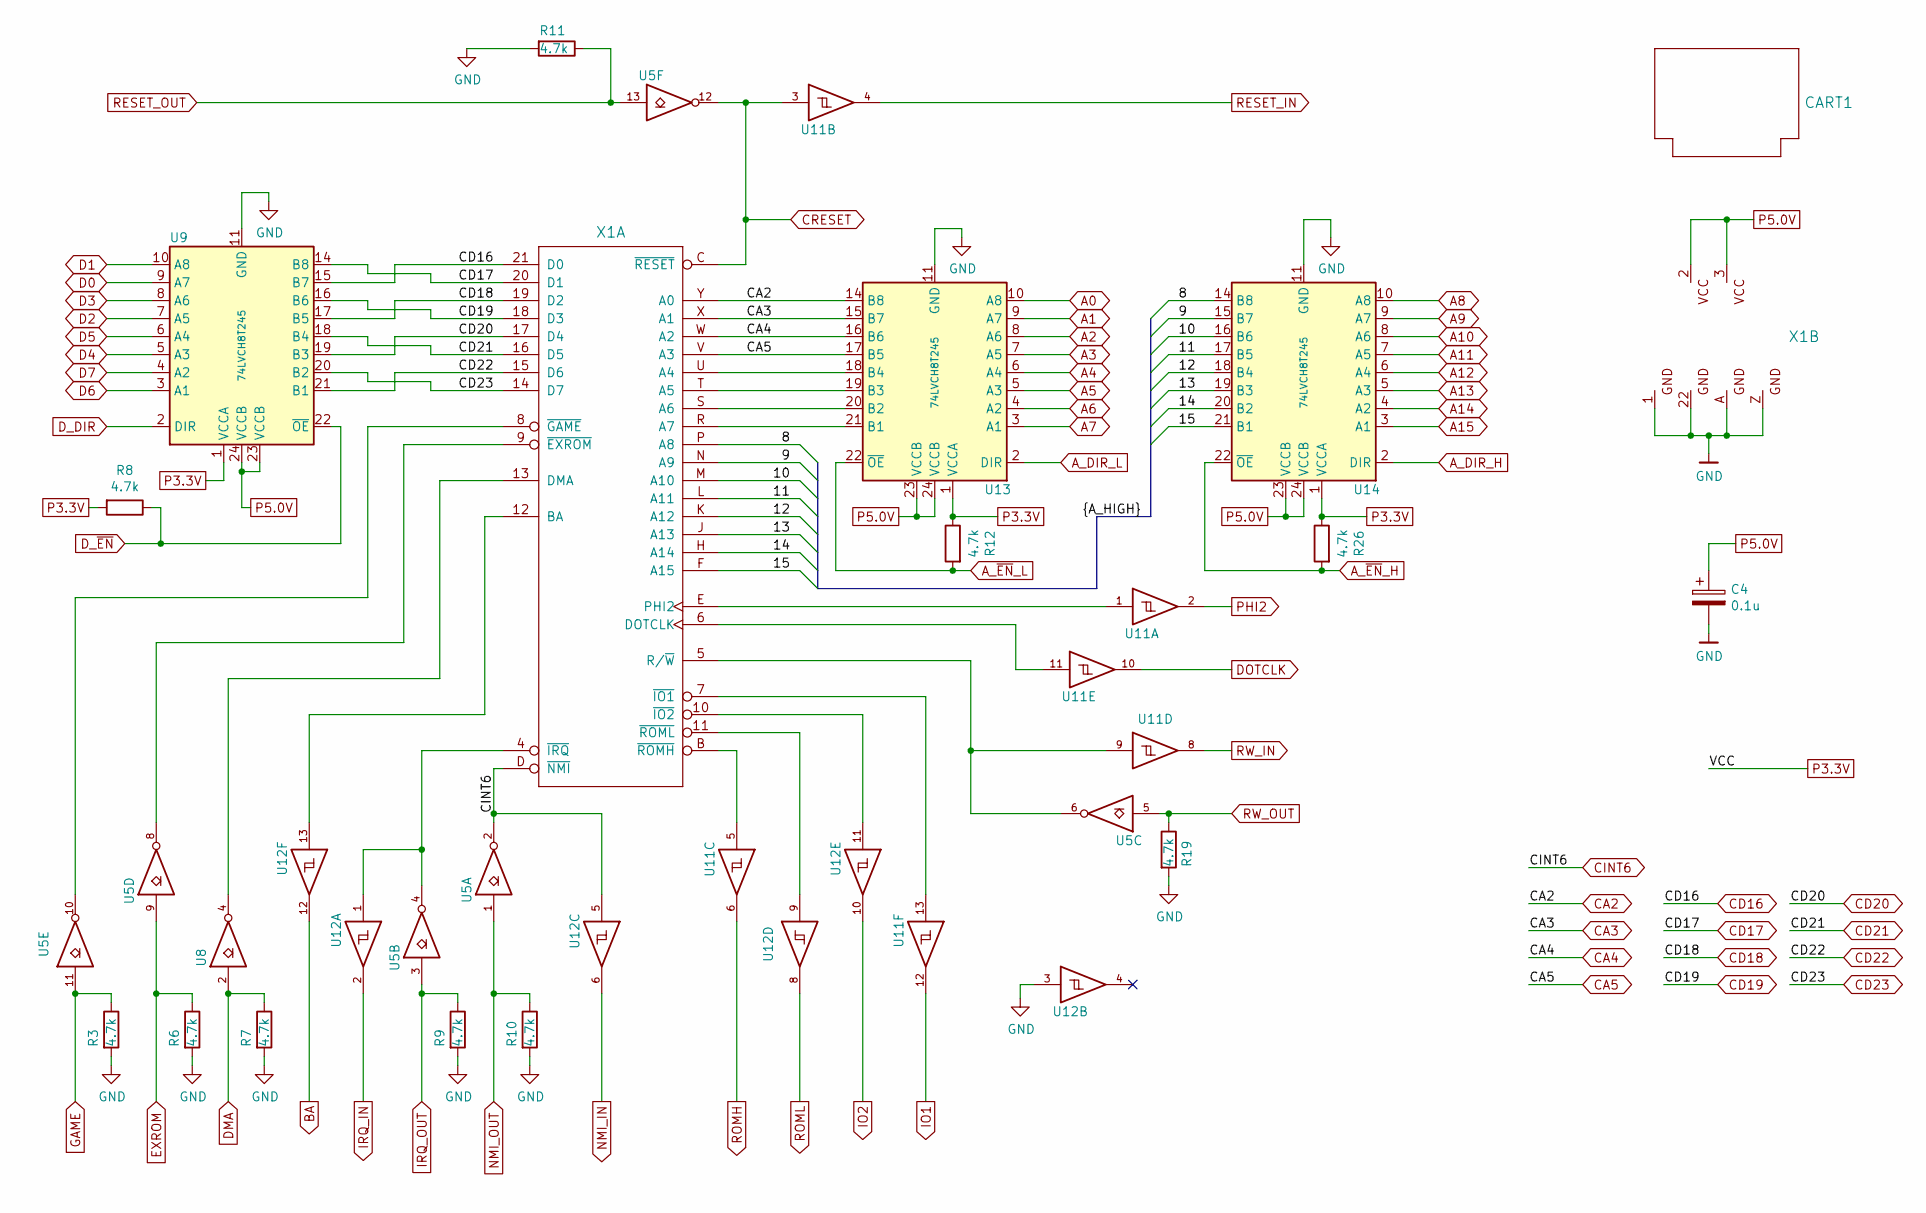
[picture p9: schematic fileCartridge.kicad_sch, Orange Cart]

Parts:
C4: 0.1u; C_0603_1608Metric; Mouser Part No 710-885012206071
CART1: CARTRIDGE_C64; CARTRIDGE_C64_GERMAN
R3, R6, R7, R8, R9, R10, R11, R12, R19, R26: 4.7k; R_0402_1005Metric; Mouser Part No 603-RC0402JR-074K7L
U5: 74LVC06A; TSSOP-14_4.4x5mm_P0.65mm; Mouser Part No 595-SN74LVC06APW
U8: 74LVC1G06; SOT-23-5; Mouser Part No 595-SN74LVC1G06DBVR
U9, U13, U14: 74LVCH8T245; TSSOP-24_4.4x7.8mm_P0.65mm; Mouser Part No 771-4LVCH8T245PWQ10J
U11, U12: 74AHCV17A; TSSOP-14_4.4x5mm_P0.65mm; Mouser Part No 771-74AHCV17APWJ
X1: EXPANSION_PORT_C64_EDGE; MA100-22-2

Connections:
/sheetCartridge/8: U14.14 (B8), X1.P (A8)
/sheetCartridge/9: U14.15 (B7), X1.N (A9)
/sheetCartridge/10: U14.16 (B6), X1.M (A10)
/sheetCartridge/11: U14.17 (B5), X1.L (A11)
/sheetCartridge/12: U14.18 (B4), X1.K (A12)
/sheetCartridge/13: U14.19 (B3), X1.J (A13)
/sheetCartridge/14: U14.20 (B2), X1.H (A14)
/sheetCartridge/15: U14.21 (B1), X1.F (A15)
A0: U13.10 (A8); also elsewhere on the board
A1: U13.9 (A7); also elsewhere on the board
A2: U13.8 (A6); also elsewhere on the board
A3: U13.7 (A5); also elsewhere on the board
A4: U13.6 (A4); also elsewhere on the board
A5: U13.5 (A3); also elsewhere on the board
A6: U13.4 (A2); also elsewhere on the board
A7: U13.3 (A1); also elsewhere on the board
A8: U14.10 (A8); also elsewhere on the board
A9: U14.9 (A7); also elsewhere on the board
A10: U14.8 (A6); also elsewhere on the board
A11: U14.7 (A5); also elsewhere on the board
A12: U14.6 (A4); also elsewhere on the board
A13: U14.5 (A3); also elsewhere on the board
A14: U14.4 (A2); also elsewhere on the board
A15: U14.3 (A1); also elsewhere on the board
A_DIR_H: U14.2 (DIR); also elsewhere on the board
A_DIR_L: U13.2 (DIR); also elsewhere on the board
A_~EN_H: R26.2, U14.22 (~OE); also elsewhere on the board
A_~EN_L: R12.2, U13.22 (~OE); also elsewhere on the board
BA: U12.12; also elsewhere on the board
CA2: U13.14 (B8), X1.Y (A0); also elsewhere on the board
CA3: U13.15 (B7), X1.X (A1); also elsewhere on the board
CA4: U13.16 (B6), X1.W (A2); also elsewhere on the board
CA5: U13.17 (B5), X1.V (A3); also elsewhere on the board
CD16: U9.15 (B7), X1.21 (D0); also elsewhere on the board
CD17: U9.14 (B8), X1.20 (D1); also elsewhere on the board
CD18: U9.17 (B5), X1.19 (D2); also elsewhere on the board
CD19: U9.16 (B6), X1.18 (D3); also elsewhere on the board
CD20: U9.19 (B3), X1.17 (D4); also elsewhere on the board
CD21: U9.18 (B4), X1.16 (D5); also elsewhere on the board
CD22: U9.21 (B1), X1.15 (D6); also elsewhere on the board
CD23: U9.20 (B2), X1.14 (D7); also elsewhere on the board
CINT6: U5.2, U12.5, X1.D (~NMI); also elsewhere on the board
CRESET: U5.12, U11.3, X1.C (~RESET); also elsewhere on the board
D0: U9.9 (A7); also elsewhere on the board
D1: U9.10 (A8); also elsewhere on the board
D2: U9.7 (A5); also elsewhere on the board
D3: U9.8 (A6); also elsewhere on the board
D4: U9.5 (A3); also elsewhere on the board
D5: U9.6 (A4); also elsewhere on the board
D6: U9.3 (A1); also elsewhere on the board
D7: U9.4 (A2); also elsewhere on the board
DMA: R7.1, U8.2; also elsewhere on the board
DOTCLK: U11.10; also elsewhere on the board
D_DIR: U9.2 (DIR); also elsewhere on the board
D_~EN: R8.1, U9.22 (~OE); also elsewhere on the board
EXROM: R6.1, U5.9; also elsewhere on the board
GAME: R3.1, U5.11; also elsewhere on the board
GND: C4.2, R3.2, R6.2, R7.2, R9.2, R10.2, R11.2, R19.2, U5.7 (GND), U8.3 (GND), U9.11 (GND), U9.12 (GND), U9.13 (GND), U11.7 (GND), U12.3, U12.7 (GND), U13.11 (GND), U13.12 (GND), U13.13 (GND), U14.11 (GND), U14.12 (GND), U14.13 (GND), X1.1 (GND), X1.22 (GND@1), X1.A (GND@2), X1.Z (GND@3); also elsewhere on the board
IO1: U11.12; also elsewhere on the board
IO2: U12.10; also elsewhere on the board
IRQ_IN: U12.2; also elsewhere on the board
IRQ_OUT: R9.1, U5.3; also elsewhere on the board
NMI_IN: U12.6; also elsewhere on the board
NMI_OUT: R10.1, U5.1; also elsewhere on the board
unnamed: U13.21 (B1), X1.R (A7)
unnamed: U13.20 (B2), X1.S (A6)
unnamed: U13.19 (B3), X1.T (A5)
unnamed: U13.18 (B4), X1.U (A4)
unnamed: U12.13, X1.12 (BA)
unnamed: U8.4, X1.13 (DMA)
unnamed: U11.11, X1.6 (DOTCLK)
unnamed: U11.1, X1.E (PHI2)
unnamed: U5.6, U11.9, X1.5 (R/~W)
unnamed: U5.8, X1.9 (~EXROM)
unnamed: U5.10, X1.8 (~GAME)
unnamed: U11.13, X1.7 (~IO1)
unnamed: U12.11, X1.10 (~IO2)
unnamed: U5.4, U12.1, X1.4 (~IRQ)
unnamed: U11.5, X1.B (~ROMH)
unnamed: U12.9, X1.11 (~ROML)
P3.3V: R8.2, R12.1, R26.1, U5.14 (VCC), U8.5 (VCC), U9.1 (VCCA), U11.14 (VCC), U12.14 (VCC), U13.1 (VCCA), U14.1 (VCCA); also elsewhere on the board
P5.0V: C4.1, U9.23 (VCCB), U9.24 (VCCB), U13.23 (VCCB), U13.24 (VCCB), U14.23 (VCCB), U14.24 (VCCB), X1.2 (VCC), X1.3 (VCC@1); also elsewhere on the board
PHI2: U11.2; also elsewhere on the board
RESET_IN: U11.4; also elsewhere on the board
RESET_OUT: R11.1, U5.13; also elsewhere on the board
ROMH: U11.6; also elsewhere on the board
ROML: U12.8; also elsewhere on the board
RW_IN: U11.8; also elsewhere on the board
RW_OUT: R19.1, U5.5; also elsewhere on the board

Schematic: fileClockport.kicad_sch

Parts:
J1: Conn_02x11_Odd_Even; PinHeader_2x11_P2.00mm_Vertical; Mouser Part No 200-TMM11103GD
RN1: 10K; R_Array_Convex_4x0402; Mouser Part No 667-EXB-28V103JX

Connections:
CA2: J1.12; also elsewhere on the board
CA3: J1.11; also elsewhere on the board
CA4: J1.10; also elsewhere on the board
CA5: J1.9; also elsewhere on the board
CD16: J1.20; also elsewhere on the board
CD17: J1.19; also elsewhere on the board
CD18: J1.18; also elsewhere on the board
CD19: J1.17; also elsewhere on the board
CD20: J1.16; also elsewhere on the board
CD21: J1.15; also elsewhere on the board
CD22: J1.14; also elsewhere on the board
CD23: J1.13; also elsewhere on the board
CINT6: J1.3; also elsewhere on the board
CIORD: J1.7, RN1.2 (R2.1); also elsewhere on the board
CIOWR: J1.8, RN1.1 (R1.1); also elsewhere on the board
CRESET: J1.22; also elsewhere on the board
CRTCCS: J1.5, RN1.3 (R3.1); also elsewhere on the board
CSPARECS: J1.4, RN1.4 (R4.1); also elsewhere on the board
GND: J1.1, J1.21; also elsewhere on the board
P3.3V: RN1.5 (R4.2), RN1.6 (R3.2), RN1.7 (R2.2), RN1.8 (R1.2); also elsewhere on the board
P5.0V: J1.2; also elsewhere on the board

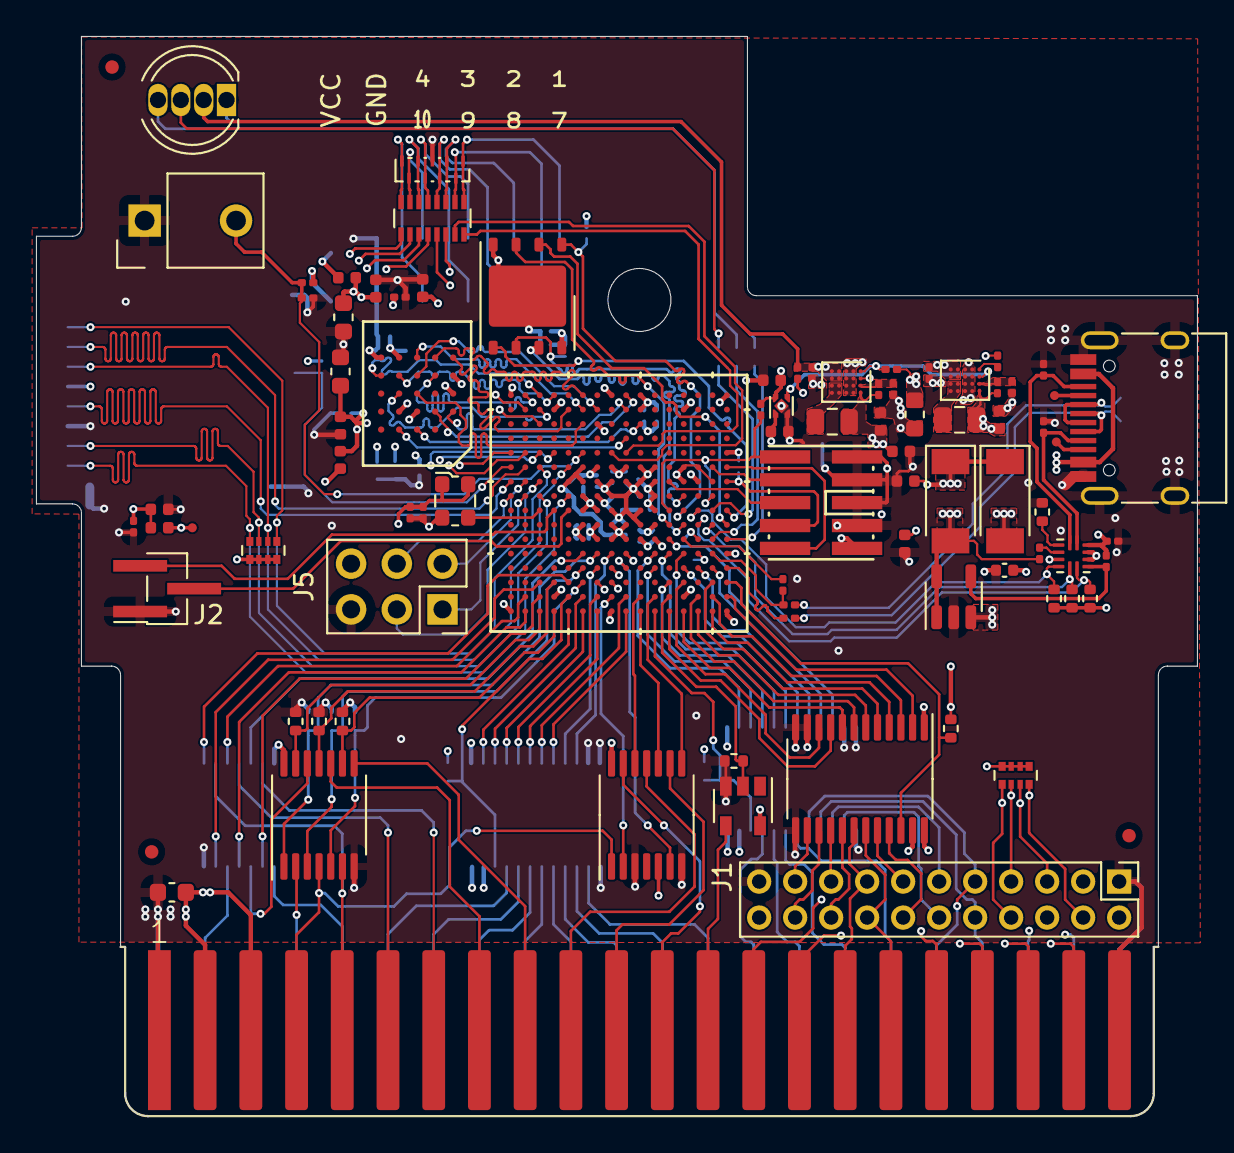
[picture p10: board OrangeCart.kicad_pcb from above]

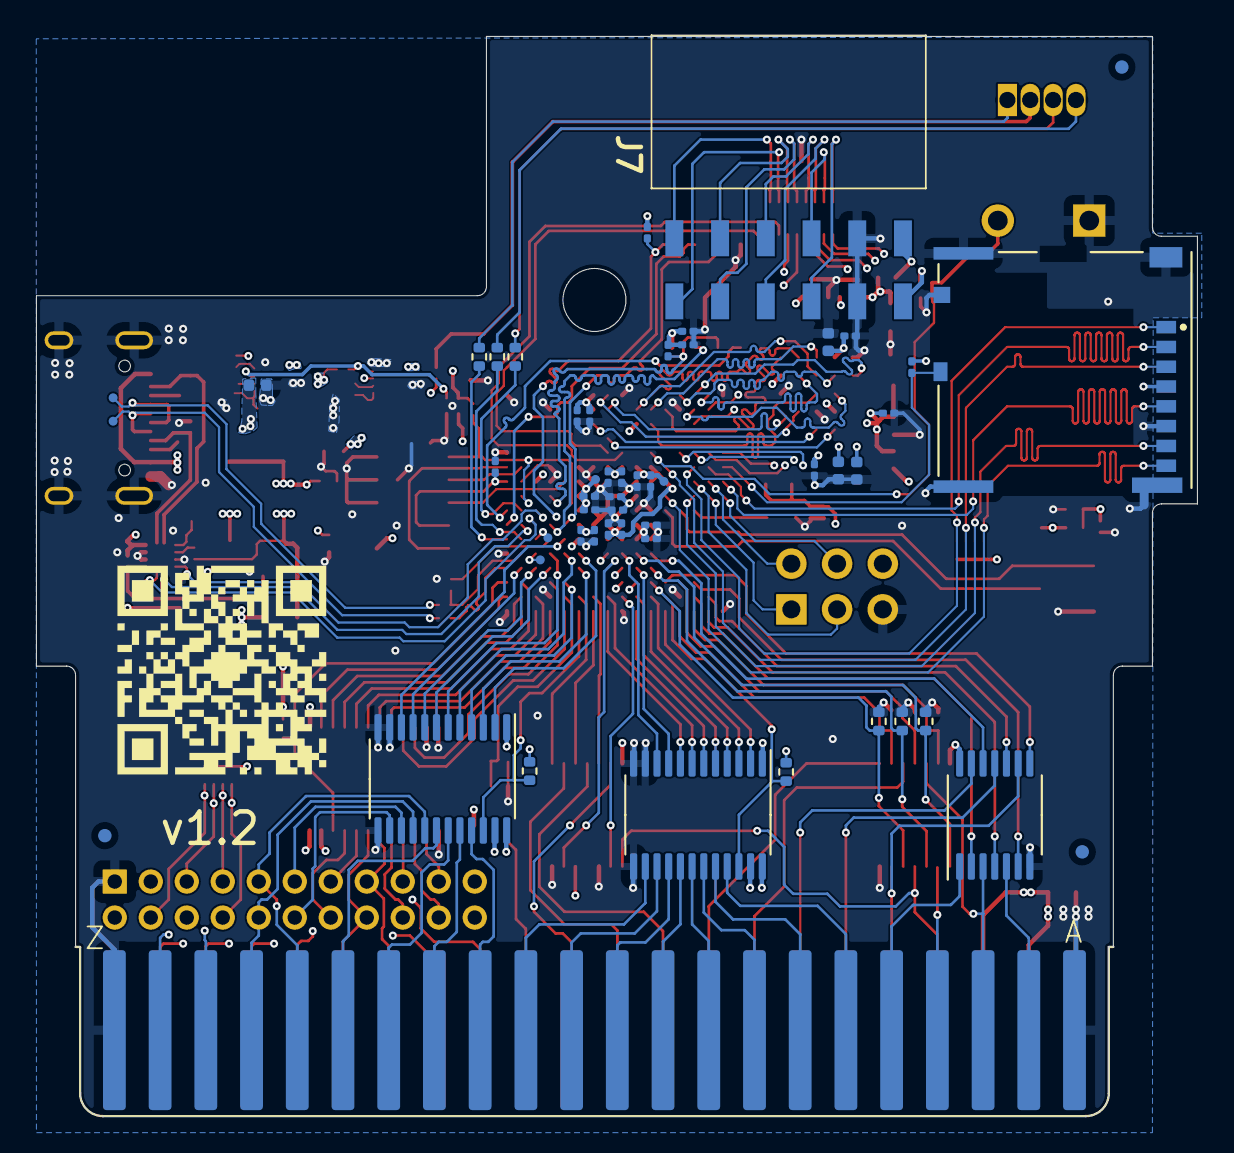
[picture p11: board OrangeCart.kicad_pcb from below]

Board: 4 copper layers, 64.5 x 60.0 mm, 140 parts (52 on the bottom side), 185 nets.

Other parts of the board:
QR1: qr

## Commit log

2021-02-28 Add 3d model for diodes
    [OrangeCart.kicad_pcb]
2021-03-14 Add clockport
    [OrangeCart.kicad_pcb, OrangeCart.sch, decopling.sch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]
2021-03-14 Add pullups of clockport signals
    [OrangeCart.kicad_pcb, fileClockport.sch, fileFPGA.sch]
2021-03-14 Retune RAM_PSC
    [OrangeCart.kicad_pcb]
2021-03-14 Fix bank 6 voltage indication in schematic
    [fileFPGA.sch]
2021-03-14 Keep out copper pour from card edge connector, and hide references
    [OrangeCart.kicad_pcb]
2021-03-14 Move stuff around in preparation for USB mini-B connector
    [OrangeCart.kicad_pcb, fileFPGA.sch]
2021-03-14 Replace USB micro-B connector with mini-B
    [OrangeCart.kicad_pcb, fileIO.sch]
2021-03-28 Update BOM with Mouser sourcing information
    [decopling.sch, fileCartridge.sch, fileClockport.sch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]
2021-03-30 Length match SPI flash and SDCARD signals
    [OrangeCart.kicad_pcb]
2021-03-30 Add QR code
    [OrangeCart.kicad_pcb]
2021-04-12 Remove solder paste on card edge connector
    [OrangeCart.kicad_pcb]
2021-05-19 Increase via annular, and decrease min clearance
    [OrangeCart.kicad_pcb]
2021-05-19 Replace schematic symbol of FPGA with 0.8mm pitch version
    [fileFPGA.sch, filePOWER.sch]
2021-05-19 Replace footprint of FPGA with 0.8mm pitch version
    [OrangeCart.kicad_pcb, fileFPGA.sch]
2021-05-20 Mark I/O banks
    [OrangeCart.kicad_pcb, fileFPGA.sch]
2021-05-20 Swap bank 2 and 6
    [OrangeCart.kicad_pcb, fileFPGA.sch]
2021-05-20 Increase via size
    [OrangeCart.kicad_pcb]
2021-05-22 Fix remaining DRC violations after dimension changes
    [OrangeCart.kicad_pcb]
2021-05-22 Move USB tracks
    [OrangeCart.kicad_pcb, fileFPGA.sch]
2021-05-22 Reconnect JTAG
    [OrangeCart.kicad_pcb]
2021-05-22 Reconnect QSPI and LED
    [OrangeCart.kicad_pcb, fileFPGA.sch]
2021-05-22 Reconnect RAM
    [OrangeCart.kicad_pcb, fileFPGA.sch]
2021-05-23 Reconnect SDCARD and add a serial port
    [OrangeCart.kicad_pcb, fileFPGA.sch, fileSDMMC.sch]
2021-05-23 Move tracks from inner layer 2 to 3
    [OrangeCart.kicad_pcb]
2021-05-23 Reconnect expansion port
    [OrangeCart.kicad_pcb, fileFPGA.sch]
2021-05-23 Disable I/O bank 0 and 3
    [OrangeCart.kicad_pcb, decopling.sch, fileFPGA.sch]
2021-05-23 Restore power and decouplings
    [OrangeCart.kicad_pcb, decopling.sch, fileFPGA.sch]
2021-05-23 Update BOM
    [OrangeCart.kicad_pcb, fileFPGA.sch]
2021-05-23 Connect some unconnected stuff
    [OrangeCart.kicad_pcb]
2021-05-23 Length match SDCARD
    [OrangeCart.kicad_pcb]
2021-05-23 Reduce layers to 4
    [OrangeCart.kicad_pcb]
2021-05-23 Hook up last two GND pins
    [OrangeCart.kicad_pcb, decopling.sch]
2021-05-24 Retune track lengths
    [OrangeCart.kicad_pcb]
2021-05-27 Rotate UART connector
    [OrangeCart.kicad_pcb]
2021-06-04 Fix BOM for pin header J1
    [fileClockport.sch]
2021-06-04 Update fab layers
    [OrangeCart.kicad_pcb]
2021-09-04 BOM update: Lower profile headers for J1 and J6
    [fileClockport.sch, fileFPGA.sch]
2021-09-04 Replace LED with THT version
    [OrangeCart.kicad_pcb, fileIO.sch]
2021-09-04 Replace pushbutton with THT version
    [OrangeCart.kicad_pcb, fileIO.sch]
2021-09-04 Moved fiducials
    [OrangeCart.kicad_pcb]
2021-09-04 Add copper pour to front layer
    [OrangeCart.kicad_pcb]
2021-09-04 Move UART connector
    [OrangeCart.kicad_pcb]
2021-09-17 Adjust RGB LED resistors after measurements
    Measurement over resistors in testbench gave
    R: 2.52V -> 210 ohm for 12.0 mA
    G: 1.5V -> 124 ohm for 12.1 mA
    B: 1.48V -> 124 ohm for 11.9 mA
    [OrangeCart.kicad_pcb, fileIO.sch]
2021-10-05 Add some more margin between traces and board edge
    [OrangeCart.kicad_pcb]
2021-10-16 Adjust screw hole position
    [OrangeCart.kicad_pcb]
2021-10-17 Change SDcard part
    [OrangeCart.kicad_pcb, fileSDMMC.sch]
2021-11-20 BOM update: Replace OSC1 with more readily available part
    [OrangeCart.kicad_pcb, fileFPGA.sch]
2021-12-04 Update 3D models for pin headers
    [OrangeCart.kicad_pcb]
2021-12-05 Change oscillator from 25 ppm to 50 ppm part (25 ppm was a mistake)
    [fileFPGA.sch]
2022-01-14 Replace USB connector with type C
    [OrangeCart.kicad_pcb, fileIO.sch]
2022-01-23 Add 4 GPIOs on a sort of "Pmod" connector
    [OrangeCart.kicad_pcb, fileFPGA.sch, fileIO.sch]
2022-01-25 Move USB connector 0.05 mm right to provide 1.85 mm clearance to plug
    [OrangeCart.kicad_pcb]
2022-01-26 Change USB-C connector to variant with longer stakes
    [fileIO.sch]
2022-02-06 Update measurements
    [OrangeCart.kicad_pcb]
2022-02-11 Align BOM with P1 order
    [fileCartridge.sch, fileFPGA.sch]
2022-02-12 Use new 3D model for USB-C connector
    [OrangeCart.kicad_pcb]
2022-02-14 Update OSC1 footprint
    [OrangeCart.kicad_pcb, fileFPGA.sch]
2022-04-09 Add weak pull-up resistor to FPGA_RESET
    [OrangeCart.kicad_pcb, fileFPGA.sch]
2022-04-30 Change HyperRAM to one with less excessive temperature range
    [fileHyperRAM.sch]
2022-04-30 Add version number on silkscreen
    [OrangeCart.kicad_pcb]
2022-09-25 Convert to KiCAD 6
    [OrangeCart.kicad_pcb, OrangeCart.kicad_sch, OrangeCart.sch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]
2022-09-25 Fix solder mask color
    [OrangeCart.kicad_pcb]
2022-09-25 Fix some checker complaints
    [OrangeCart.kicad_pcb, OrangeCart.kicad_sch, fileCartridge.kicad_sch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]
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2022-09-25 Replace HyperRAM with 3V Winbond part
    Also remove PSC/PSC# as they are not used on 3V parts.
    [OrangeCart.kicad_pcb, OrangeCart.kicad_sch, decopling.kicad_sch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]
2022-09-25 Remove 1.8V power supply
    [OrangeCart.kicad_pcb, OrangeCart.kicad_sch, fileIO.kicad_sch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]
2022-09-25 Make traces on inner layers thicker
    [OrangeCart.kicad_pcb]
2022-09-25 Add NMI and IRQ inputs
    [OrangeCart.kicad_pcb, OrangeCart.kicad_sch, fileCartridge.kicad_sch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]
2022-09-25 Update datasheet link for HyperRAM
    [fileHyperRAM.kicad_sch]
2022-09-25 Redo routing to memories
    [OrangeCart.kicad_pcb, OrangeCart.kicad_sch, fileCartridge.kicad_sch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]
2022-09-25 Fix U12 silkscreen and fab
    [OrangeCart.kicad_pcb]
2022-09-25 Adjust paste on U10 so that it doesn't extend outside mask
    [OrangeCart.kicad_pcb]
2022-09-25 Add a dual PMOD connector with official shape
    [OrangeCart.kicad_pcb, OrangeCart.kicad_sch, fileFPGA.kicad_sch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]
2022-09-25 Replace 8-channel level shifters with LVCH variant
    The "H" makes them consume less current when the inputs are floating.
    [OrangeCart.kicad_pcb, OrangeCart.kicad_sch, fileCartridge.kicad_sch]
2022-09-25 Add USB-C power management chip
    [OrangeCart.kicad_pcb, OrangeCart.kicad_sch, fileFPGA.kicad_sch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]
2022-09-25 Update version on silk screen
    [OrangeCart.kicad_pcb]
2023-07-31 Convert to KiCAD 7
    [OrangeCart.kicad_pcb, OrangeCart.kicad_sch, decopling.kicad_sch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]
2023-07-31 Add silkscreen pinout for PMOD
    [OrangeCart.kicad_pcb]
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2023-08-01 Update net names to match schematic
    [OrangeCart.kicad_pcb]
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2023-08-02 Some plotting setting updates
    [OrangeCart.kicad_pcb]
2023-08-04 Increased size of flash thermal pad
    [OrangeCart.kicad_pcb]

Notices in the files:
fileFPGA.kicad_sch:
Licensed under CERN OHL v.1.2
